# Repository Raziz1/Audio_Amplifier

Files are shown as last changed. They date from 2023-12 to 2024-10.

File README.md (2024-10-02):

# Audio_Amplifier 🔊
Designing a push–pull audio amplifier for a car speaker

## Goal 🎯
The goal of this project was to design a simple audio amplifier to drive a 4-ohm, 30-watt RMS (42 Watt peak) speaker extracted from a car door. The objective was not to create the most efficient design, but rather to explore various design approaches.

<p align="center">
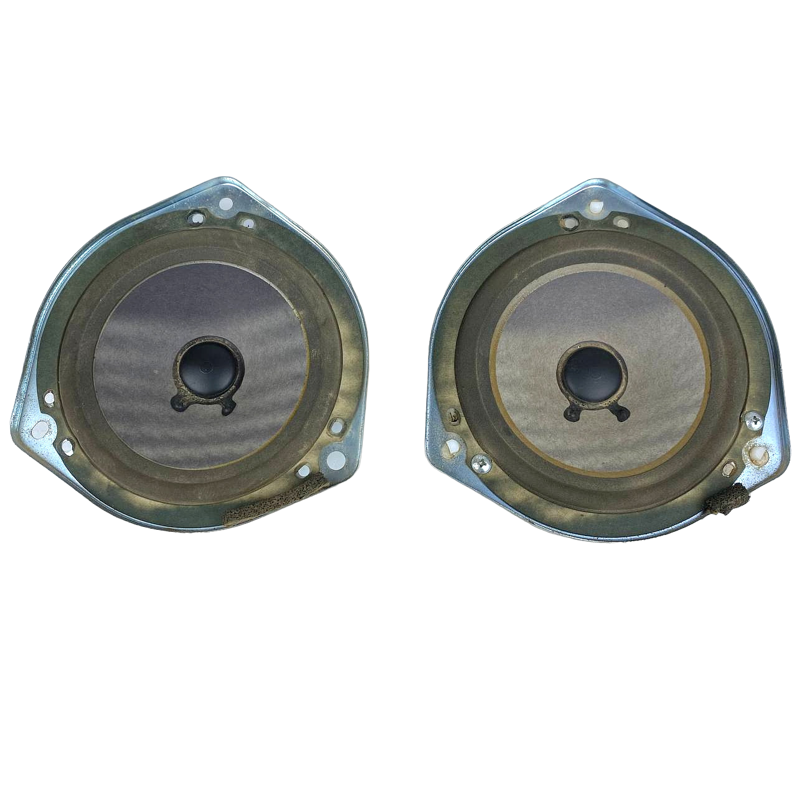
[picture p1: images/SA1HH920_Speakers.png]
  
</p>

## To-do List 📃
- [x] Pick amplifier class
- [x] Pick power stage amplifier
- [x] Design and simulate in LTSPICE
- [x] Pick components with appropriate ratings
- [x] Determine thermal output of transistors
- [x] PCB design
- [ ] Testing

## History 📃
Initially, I began by driving the speaker with my USB oscilloscope/waveform generator (Analog Discovery 2). The USB waveform generator has the ability to take an MP3 file as an input and output the corresponding waveform. It also has the ability to amplify the signal up to a peak voltage of 5V. However, there were a few problems with this:
1. According to the datasheet, this waveform generator has the ability to output a maximum current of 750mA. At a peak voltage of 5V, the power output would only be (0.75A x 5V = 3.75W peak * 0.707 = 2.65W RMS) 2.65 watts RMS, which is only about 9% of the speaker's power output capabilities
2. When set to 5V peak output, the waveform generator only seemed to be able to push out 250mA. This means we were only achieving a power output of (0.25A * 5V = 1.25W peak * 0.707 = 0.883W RMS) 0.883 watts RMS.
3. Lastly, when set to 5V, the speaker seemed to suffer from a lot of distortion and resulted in very muddy tones
4. The final motivation was to see if I could drive the speaker significantly louder. With a 1V waveform signal the loudest sound seemed to be around *INSERT DB MEASUREMENT*

## Constraints ⚠️
While devising the design for this project, I established a few constraints to prevent overcomplication. The constraints/rules I settled on were as follows:
* The input/audio signal would be anywhere from 100mV to 1V
* I didn't have to make use of the full 30 watt power capabilities of the speaker

# Audio Amplifier Background
To drive a speaker louder (higher output power) there are two things to keep in mind. These elements are evident in the power equation $P = V × I$. To acheive a higher output power we must amplify both voltage and current. Achieving greater output power necessitates amplifying both voltage and current. Therefore, we divide our amplifier design into two stages: the voltage/signal amplifier stage and the current/power amplifier stage. This practice is widely employed in all types of audio amplifiers.

The subsequent step in the process involved determining the preferred classification of audio amplifiers for this design. There are four main classes: A, B, AB, and Class D. Further information about these classifications can be found in the links provided below.

<p align="center">
  
</p>

### Class A Amplifiers
* Transistors conduct over the entire 360° cycle of the input signal
* Highest linearity and fidelity, with minimal crossover distortion
* Very inefficient, with typical efficiency around 25% due to constant current draw
* Significant heat dissipation and power wastage, even with no input signal
* Used in low-power applications where sound quality is the top priority

### Class B Amplifiers
* Use a pair of transistors, each conducting for 180° of the input signal cycle
* Improved efficiency over Class A, up to 78% theoretical maximum
* Suffer from crossover distortion around the zero-crossing point when transitioning between transistors
* Reduced heat dissipation compared to Class A
* Used in applications where efficiency is more important than linearity

### Class AB Amplifiers
*Combine the high efficiency of Class B with the low distortion of Class A
* Bias both transistors to conduct for slightly more than 180° to eliminate crossover distortion
* Efficiency up to 60%, lower than Class B but higher than Class A
* Moderate heat dissipation, less than Class A but more than Class B
* Popular choice for high-fidelity audio amplifiers, balancing efficiency and sound quality

I ended up settling on designing a Class AB amplifier due to its compromise between efficiency and fidelity.

The second decision was whether to use MOSFETs or BJTs for the power stage amplifier. I ultimately chose MOSFETs for the following reasons:
* They generally have high input impedance, which reduces the loading effect on the preceding stages
* They require no current to drive the gate pin
* They can switch faster than BJTs, which can be beneficial in certain applications
* Reduced distortion compared to some BJT designs
* The only drawback is they tend to be more expensive than BJT's

### Initial Class A Design
My initial design was based on the class A amplifier design, as shown in the image below. However, the issue arose from its excessive current draw from the op-amp. Additionally, in the absence of a signal input, the amplifier continues to conduct large amounts of current, which could potentially damage the speaker.

<p align="center">
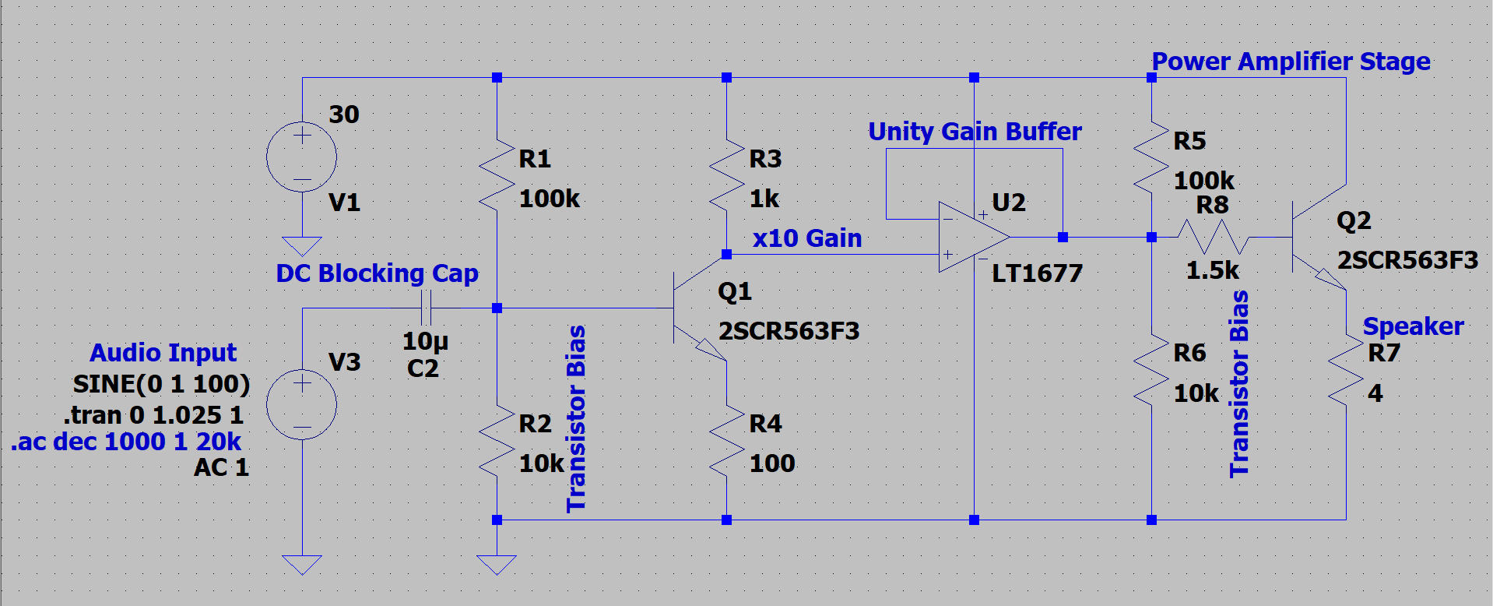
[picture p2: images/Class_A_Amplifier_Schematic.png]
  
  <p align="center"><small><i>Class A Amplifier Design in LTSpice</i></small</p>
</p>

<p align="center">
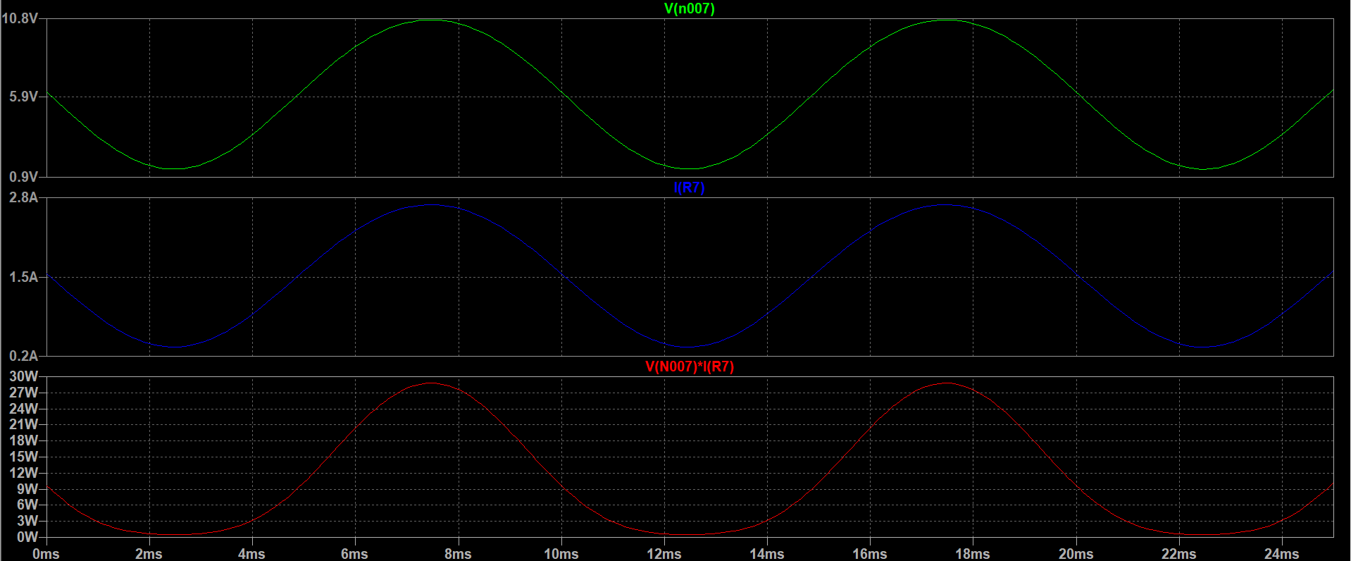
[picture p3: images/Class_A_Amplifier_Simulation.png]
  
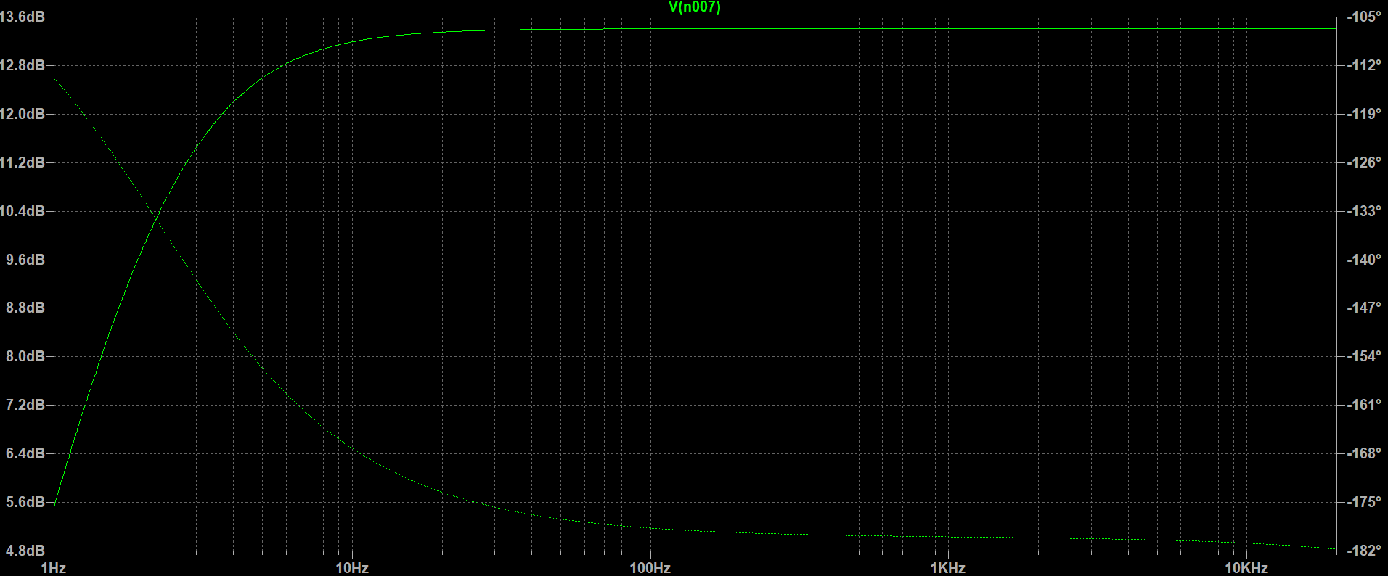
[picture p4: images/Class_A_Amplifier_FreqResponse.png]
  

  <p align="center"><small><i>Class A Amplifier Simulation in LTSpice</i></small</p>
</p>

# Final Class AB Design
## Schematic
<p align="center">
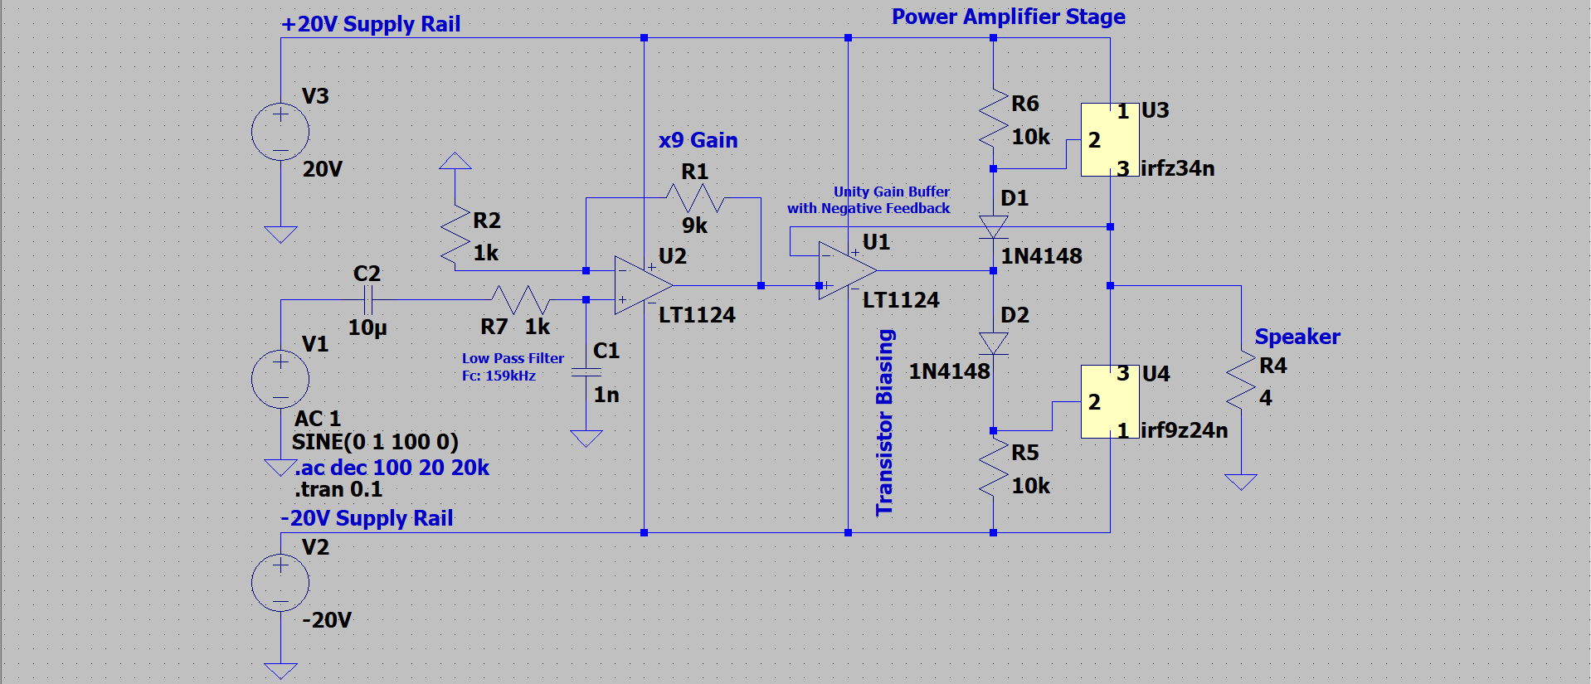
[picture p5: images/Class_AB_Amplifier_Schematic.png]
  
  <p align="center"><small><i>Class AB Amplifier LTSpice Schematic Capture</i></small></p>
</p>

* For this design, I ended up choosing the LT1124 op-amp for the signal amplifying stage. There were a couple of reasons behind this decision. Initially, I had planned for that stage to use a common emitter amplifier. However, the issue was that it required fine-tuning to determine the bias voltages. Additionally, by using the LT1124 op-amp, I could incorporate a potentiometer for variable gain ranging from 0 to 10dB.
* For the power stage of this amplifier, I ended up utilizing the op-amp's inverting terminal as a negative feedback loop for the push-pull configuration. This allowed me to avoid fine-tuning the bias voltages with resistors and diodes.

## Simulation
<p align="center">
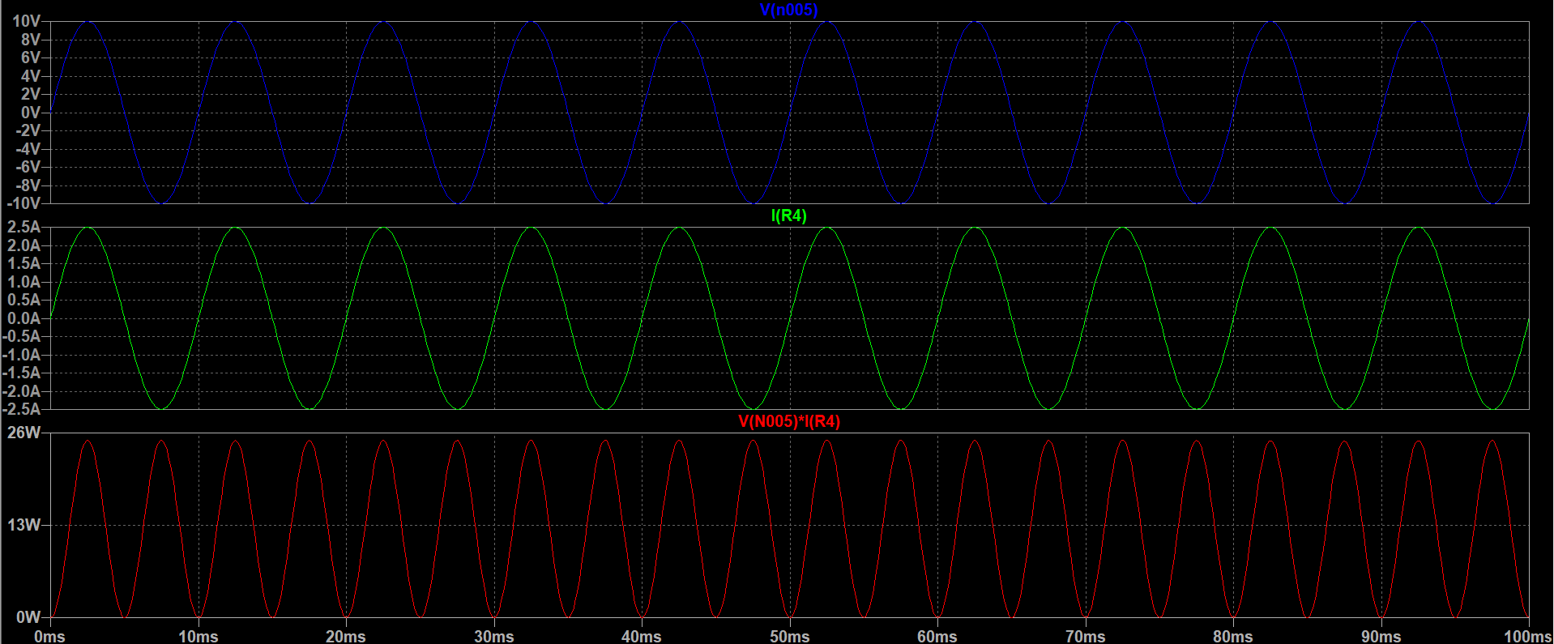
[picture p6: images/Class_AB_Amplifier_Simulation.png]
  
  <p align="center"><small><i>[1]Output Voltage [2]Output Current [3]Output Power</i></small</p>
</p>

<p align="center">
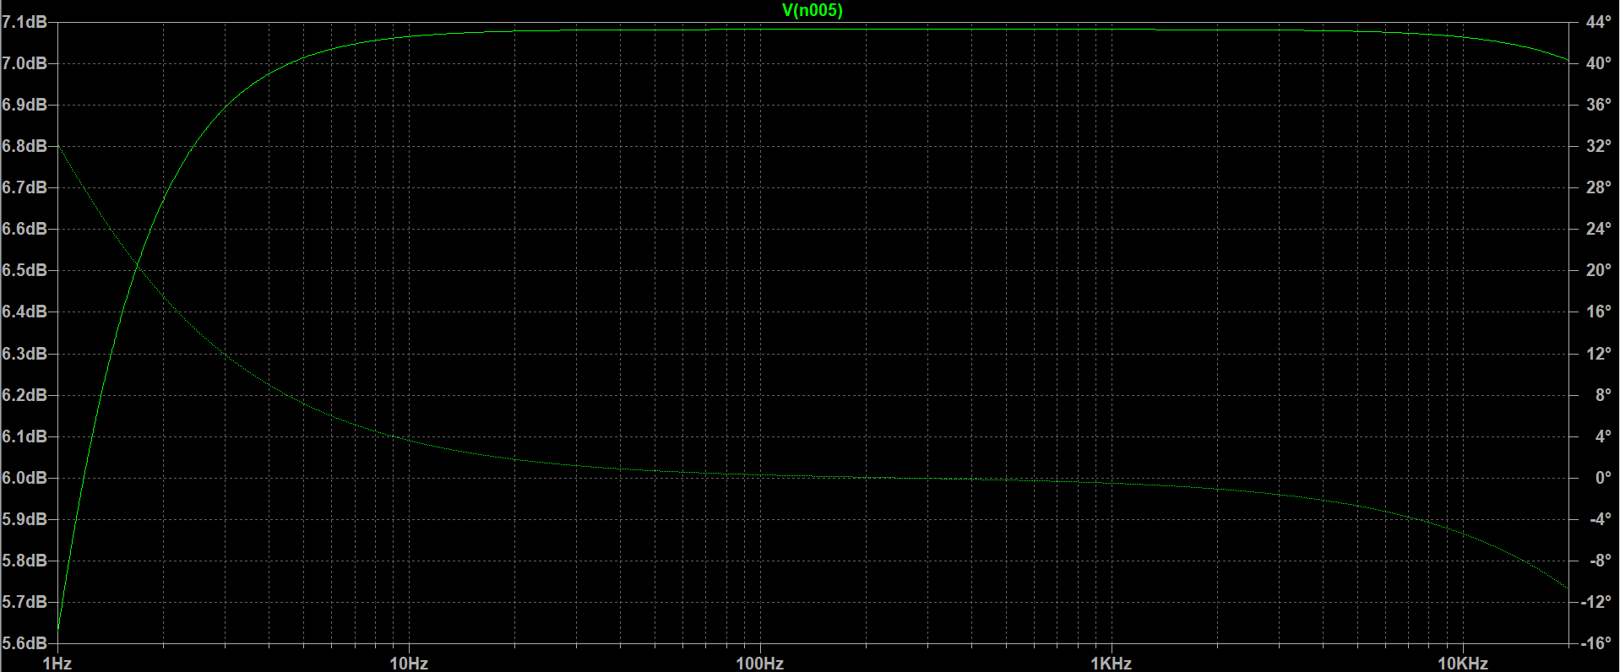
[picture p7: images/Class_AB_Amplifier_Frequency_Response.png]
  
  <p align="center"><small><i>Amplifier Frequency Response 1Hz - 20kHz</i></small</p>
</p>

* For the spice simulation of the MOSFETs, custom models were obtained online through Infineon's website. The custom models can be found in the *spice_models* folder.

# Parts
## OP-AMP
I ended up settling on the [LT1124](https://www.analog.com/en/products/lt1124.html)
* Power supply range: ±22V (Dual rail supplies)
* Slew rate: 3.9 - 4.5 V/us
  * To maintain high fidelity audio it is recommended to have a slew rate of +5V/us.
  * We can determine the minimum slew rate given the expected output voltage and frequency. Our maximum output voltage should be 10V and our maximum frequency should be around 20kHz (The upper limit of human hearing). Using the slew rate formula ($Slew Rate = 2πfv$)
  * $Minimum Slew Rate = 2 * π * 20000 * 10 = 1.256V/μS$ 
* Gain-Bandwidth product: 12.5MHz
* Low voltage noise: 2.7nV/√Hz Typ

## N-MOSFET
I ended up settling on the [IRFZ34NPBF](https://www.digikey.ca/en/products/detail/infineon-technologies/IRFZ34NPBF/811724)
* Maximum VDS: 55V
* Continuous drain current: 29A
* Maximum power dissipation: 68W
  * No additional cooling is required since we will not exceed this power rating
* Gate to source voltage: ±20V
* Gate threshold voltage: 2-4V
* RDS(ON): 0.04 ohms
* Turn-on delay time: 7ns
* Rise time: 49ns
* Turn-off delay time: 31ns
* Fall time: 40ns
* Input capacitanceL 700pF

## P-MOSFET
I ended up settling on the [IRF9Z24NPBF](https://www.digikey.ca/en/products/detail/infineon-technologies/IRF9Z24NPBF/811747)
* Maximum VDS: -55V
* Continuous drain current: -12A
* Maximum power dissipation: 45W
  * No additional cooling is required since we will not exceed this power rating
* Gate to source voltage: ±20V
* Gate threshold voltage: (-2V)-(-4V)
* RDS(ON): 0.175 ohms
* Turn-on delay time: 13ns
* Rise time: 55ns
* Turn-off delay time: 23ns
* Fall time: 37ns
* Input capacitanceL 350pF

*Both MOSFET's chosen are overkill for our purposes but provide sufficient headroom for error and/or future upgrades*

## N-MOSFET Junction Temperature Calculation
$Pavg = (Irms^2 * Rds(on))/2$
 * $Irms = Ipeak/√2 = 3A / √2 = 2.12A$
 * Rds(on) = 0.040 ohms
 * $Pavg = (2.12^2A * 0.04ohms)/2 = 0.08988 W$

$Tj = Pavg * RthJA + TA$
 * $Pavg = 0.08988W$
 * $RthJA = 62W/C$
 * $TA = 25C$
 * $Tj = 0.08988W * 62W/C + 25C = 30.57C$

## P-MOSFET Junction Temperature Calculation
$Pavg = (Irms^2 * Rds(on))/2$
 * $Irms = Ipeak/√2 = 3A / √2 = 2.12A$
 * Rds(on) = 0.175 ohms
 * $Pavg = (2.12^2A * 0.175ohms)/2 = 0.3932W$
 
$Tj = Pavg * RthJA + TA$
 * $Pavg = 0.3932$
 * $RthJA = 62W/C$
 * $TA = 25C$
 * $Tj = 0.3932W * 62W/C + 25C = 49.38C$

Based on the above calculations the MOSFETs shouldn't require any additional cooling methods.

# Power Supply Consideration
This design requires a positive and negative supply of 20V. This can be done using two power supplies and setting the ground references appropriately as described in this website ([Get a positive and negative voltage output from power supply](https://forum.digikey.com/t/get-a-positive-and-negative-voltage-output-from-power-supply/10593)). Alternatively, a split power supply design is another approach; however, the desired voltage and current specifications are simply too large for any regulators on the market.

## DC Bias Alternative
Since I only had a single power supply at home, I decided to provide an alternative circuit that utilizes a single supply and injects a DC bias voltage into the audio signal. The signal is then passed through a unity gain buffer and subsequently to the push-pull amplifier configuration. The push-pull amplifier configuration serves as a power stage amplifier, enabling us to deliver more power to the speaker. Finally, a large high-pass filter is added at the end to eliminate the initial DC bias.

### DC Bias Schematic 
<p align="center">
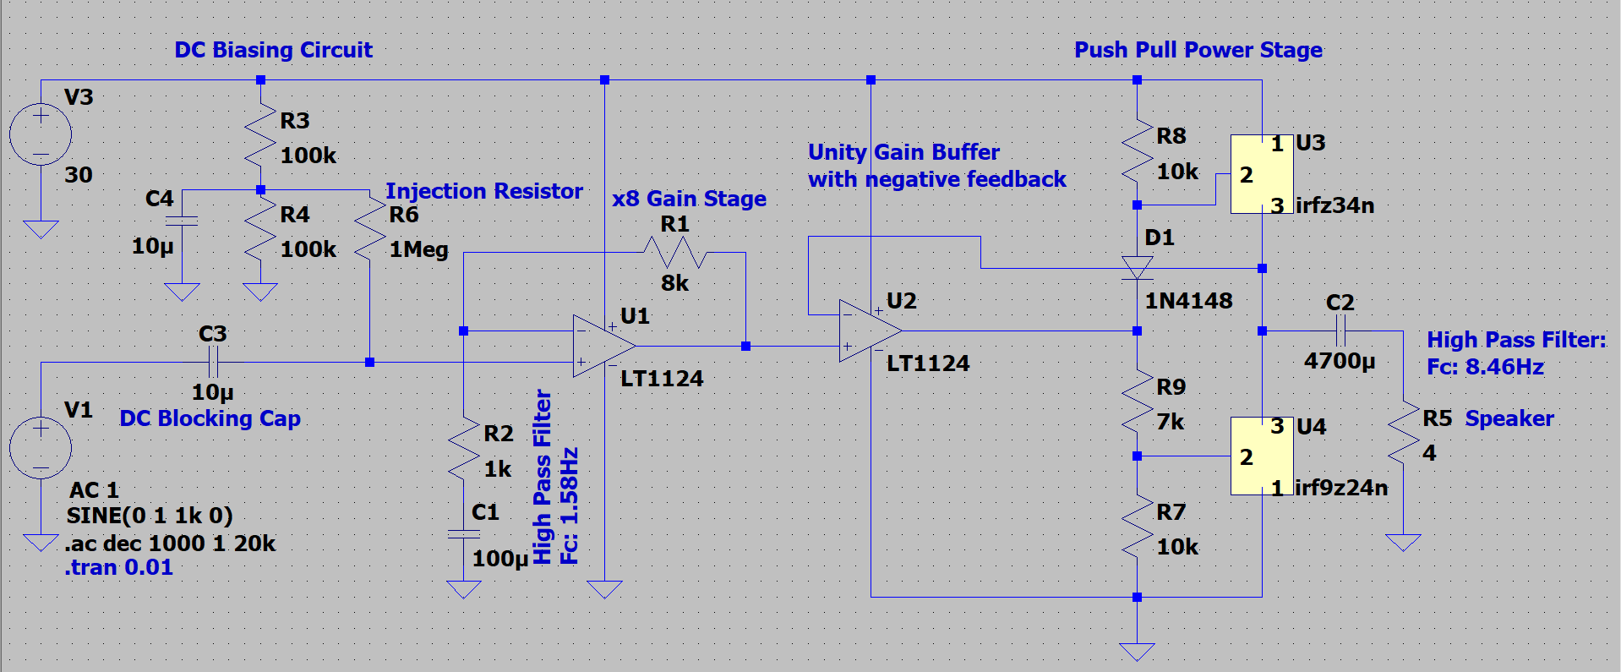
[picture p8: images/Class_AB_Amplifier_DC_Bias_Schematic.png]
  
  <p align="center"><small><i>Class AB Amplifier with DC Bias LTSpice Capture</i></small></p>
</p>

### DC Bias Simulation
<p align="center">
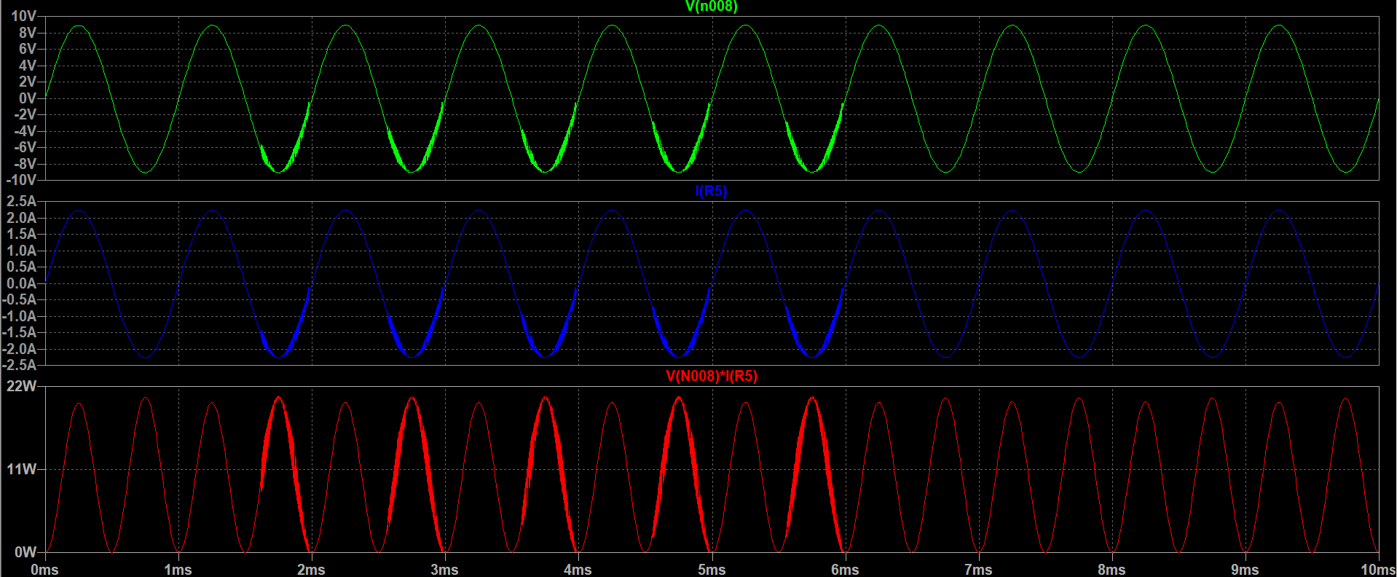
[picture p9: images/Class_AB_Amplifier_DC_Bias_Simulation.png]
  
  <p align="center"><small><i>[1]Output Voltage [2]Output Current [3]Output Power</i></small></p>
</p>

### DC Bias Frequency Response
<p align="center">
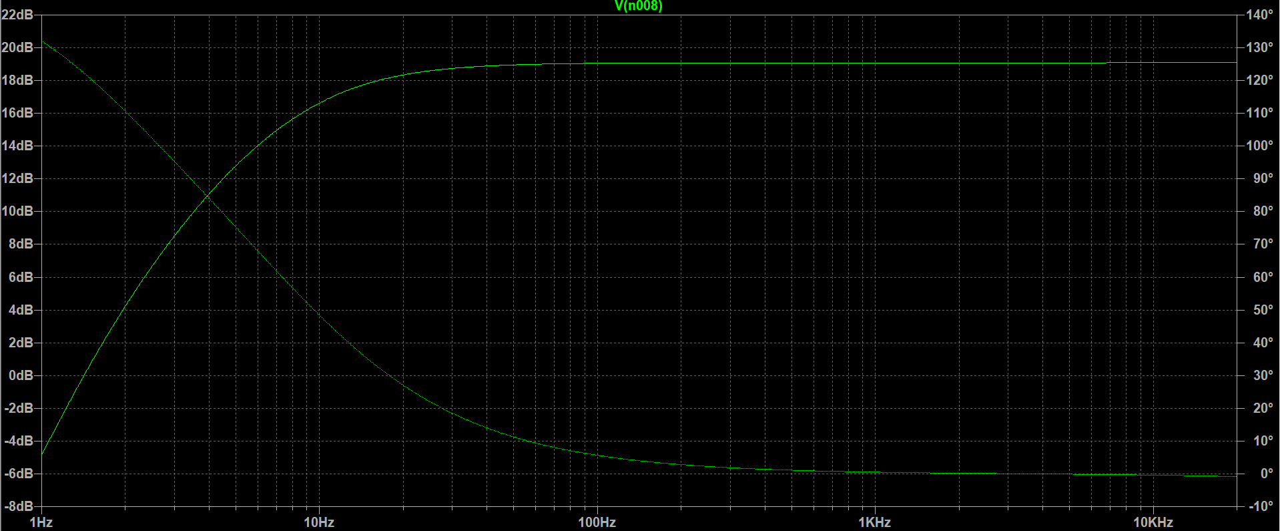
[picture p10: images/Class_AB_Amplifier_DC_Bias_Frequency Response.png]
  
  <p align="center"><small><i>DC Bias Circuit Frequency Response (1Hz - 20kHz)</i></small></p>
</p>

# PCB
The PCB design shown below is for the audio amplifier with dual supplies (+20V and -20V).

## 3D View 
<p align="center">
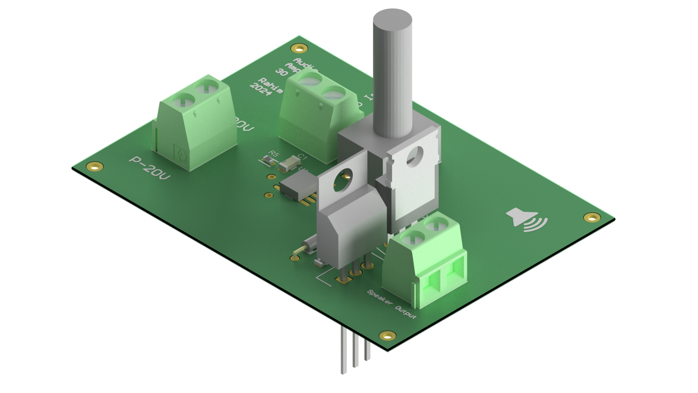
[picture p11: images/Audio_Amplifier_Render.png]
  
  <p align="center"><small><i>3D Audio Amplifier Render</i></small></p>
</p>

* One of the key considerations during this design was the use of power and ground planes. In this design, I settled on a 2 layer board design because it was cheap and simple to design. The layers are relatively thick to allow for large amounts of current to pass through the traces. However, the board might have benefited from a +20V, -20V, and GND planes. This would help dissipate heat better and reduce electromagnetic interference. 

## Power Integrity
<p align="center">
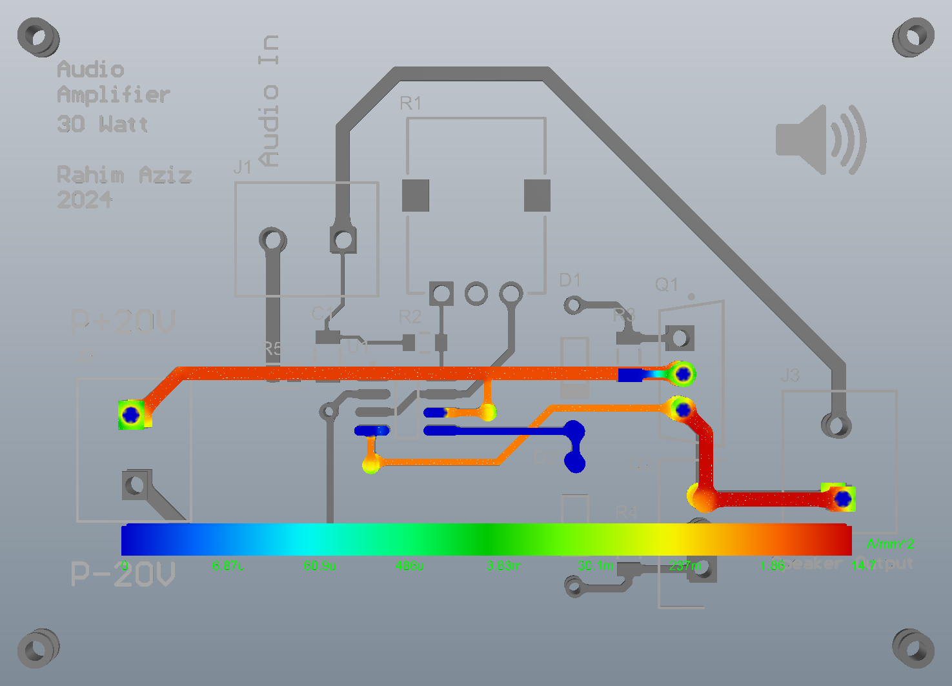
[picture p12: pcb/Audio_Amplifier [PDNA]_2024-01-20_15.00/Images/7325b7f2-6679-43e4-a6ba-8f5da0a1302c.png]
  
  <p align="center"><small><i>Power Analyzer by Keysight - Altium</i></small></p>
</p>

* I used the Saturn PCB Design Toolkit to determine the amount of current that the VIAs could handle. Based on power integrity simulations, the VIAs were more than capable of meeting the current requirements. Nevertheless, I ended up adding extra headroom for the current by increasing both the trace width and PCB thickness.

# Resources
* [Amplifier Series](https://www.youtube.com/watch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)
* [Online Circuit Simulator](https://www.falstad.com/circuit/)
* [Introduction to the Amplifier](https://www.electronics-tutorials.ws/amplifier/amp_1.html)
* [Audio Amplifier Basics](https://www.youtube.com/watch?v=U0FIG2J6Zls&ab_channel=TexasInstruments)
* [Power Amplifiers](https://en.wikipedia.org/wiki/Power_amplifier_classes#Class_C)

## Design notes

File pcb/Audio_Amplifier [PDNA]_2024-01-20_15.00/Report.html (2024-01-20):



Power Analyzer Results Report for
Audio_Amplifier

Power Analyzer Version: 1.0.16.227
Report Time / Date: 2024-01-20 2:59:55 PM
Project Name: Audio_Amplifier
Used Simulation Engine: Keysight

Power Analizer Global Settings

Parameter | Value
Metal conductivity | 58800 S/mm
Metal base conductivity | 58800 S/mm
Metal base temperature | 25°C
Metal work temperature | 25°C
Metal temperature coefficient | 0.4 %/°C
Conductor Max Current Density for Surfase Layers | 100 A/mm^2
Conductor Max Current Density for Internal Layers | 100 A/mm^2
Via wall thickness | 0.01778mm
Max Via Current Density | 0 A/mm^2
Skip ground | True

Design Stackup

# | Name | Material | Type | Thickness

| Top Overlay | | Overlay
| Top Solder | Solder Resist | Solder Mask | 0.01016mm
1 | Top Layer | | Signal | 0.2032mm
| Dielectric 1 | Core-029 | Core | 0.6096mm
2 | Bottom Layer | | Signal | 0.2032mm
| Bottom Solder | Solder Resist | Solder Mask | 0.01016mm
| Bottom Overlay | | Overlay

Full Report

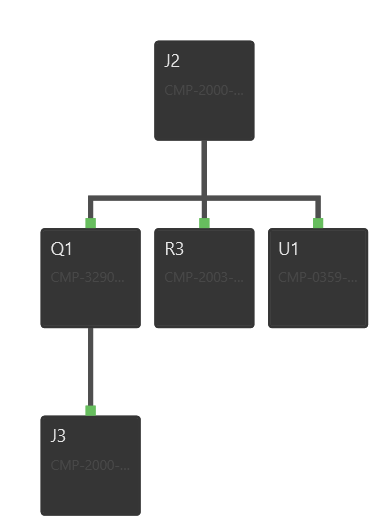
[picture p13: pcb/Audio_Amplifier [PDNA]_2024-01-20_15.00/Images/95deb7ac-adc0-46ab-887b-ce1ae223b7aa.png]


P+20V

Heatmap For Current Density

Layer: Bottom Layer


Layer: Top Layer


Heatmap For Voltage Drop

Layer: Bottom Layer


Layer: Top Layer


System-Level Power Network Results

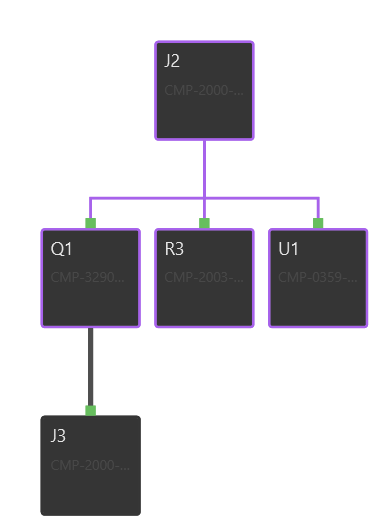
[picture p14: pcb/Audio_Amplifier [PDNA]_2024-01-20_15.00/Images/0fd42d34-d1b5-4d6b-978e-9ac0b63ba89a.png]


Network P+20V Details

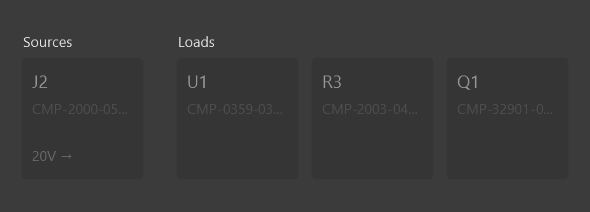
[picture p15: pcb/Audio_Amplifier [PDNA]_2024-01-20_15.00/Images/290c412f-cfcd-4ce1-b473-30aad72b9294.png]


Power Analysis Pass/Fail: Pass

Power Consumption for This Network: 0 Watts

Least Margins:

Margin Type | Absolute | Pass/Fail
Non-Via Current Density (A/mm^2) | 85.329 | Pass
Via Current (A) | 1.5745 | Pass

Margin Type (%) | Percent | Pass/Fail
Non-Via Current Density | 85.33% | Pass
Via Current | 41.48% | Pass

Failed Via Summary:

Net | Location | Drill Diameter | Max Current (A) | Actual Current (A) | Margin (%) | Max Current Density | Actual Current Density | Margin (%)
Negative_Feedback | 51.575mm : 40.85mm | 0.7112mm | 2.74 | 200.35m | 92.69% | 0 (A/mm^2) | 18.363 (A/mm^2) | ∞
P+20V | 59.85mm : 44.575mm | 0.7112mm | 2.74 | 207.17m | 92.44% | 0 (A/mm^2) | 18.988 (A/mm^2) | ∞
P+20V | 34.6mm : 44.39mm | 1.3mm | 3.8328 | 1.0771 | 71.90% | 0 (A/mm^2) | 9.8511 (A/mm^2) | ∞
P+20V | 73.67mm : 47.3mm | 1.2mm | 3.6472 | 869.97m | 76.15% | 0 (A/mm^2) | 9.3392 (A/mm^2) | ∞
Negative_Feedback | 75.25mm : 38.415mm | 1.28mm | 3.7957 | 2.2212 | 41.48% | 0 (A/mm^2) | 20.952 (A/mm^2) | ∞
Negative_Feedback | 73.67mm : 44.76mm | 1.2mm | 3.6472 | 423.04m | 88.40% | 0 (A/mm^2) | 4.5419 (A/mm^2) | ∞
Negative_Feedback | 84.95mm : 38.46mm | 1.3mm | 3.8328 | 439.1m | 88.54% | 0 (A/mm^2) | 4.0178 (A/mm^2) | ∞
NetD1_2 | 66.075mm : 40.95mm | 0.85mm | 2.9976 | 7.4118n | 100.00% | 0 (A/mm^2) | 370.76n (A/mm^2) | ∞
NetD1_2 | 66.05mm : 43.225mm | 0.85mm | 2.9976 | 5.6364n | 100.00% | 0 (A/mm^2) | 244.63n (A/mm^2) | ∞

Negative_Feedback

Heatmap For Current Density

Layer: Bottom Layer
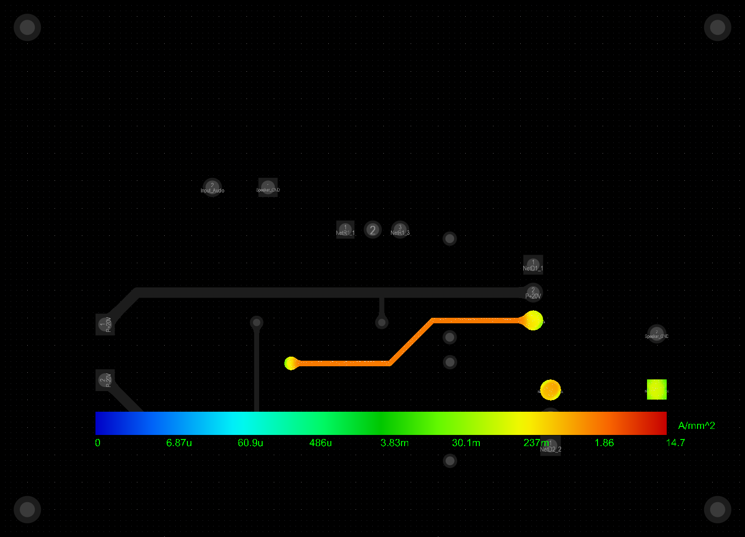
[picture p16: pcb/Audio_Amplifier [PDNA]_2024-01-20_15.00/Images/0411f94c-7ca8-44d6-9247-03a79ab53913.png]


Layer: Top Layer


Heatmap For Voltage Drop

Layer: Bottom Layer
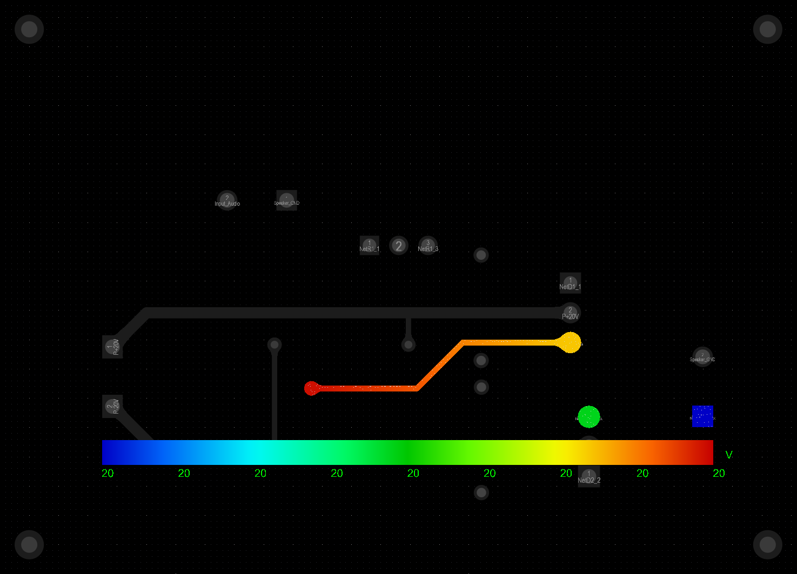
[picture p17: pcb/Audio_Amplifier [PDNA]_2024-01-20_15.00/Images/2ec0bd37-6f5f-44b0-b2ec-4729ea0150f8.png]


Layer: Top Layer
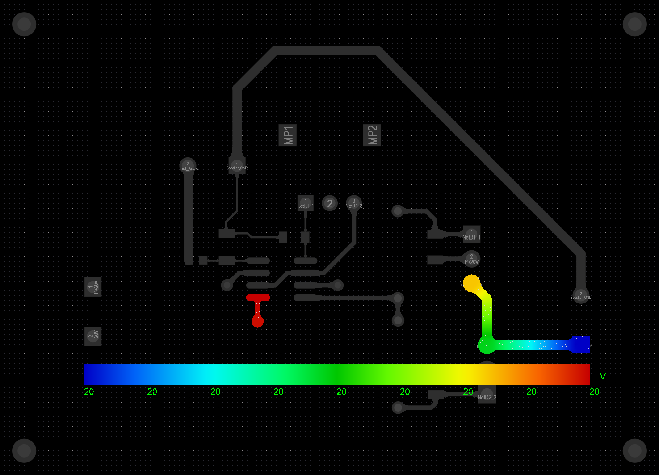
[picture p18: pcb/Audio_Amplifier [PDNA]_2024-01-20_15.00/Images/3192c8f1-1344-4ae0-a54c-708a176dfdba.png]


System-Level Power Network Results



Network Negative_Feedback Details



Power Analysis Pass/Fail: Pass

Power Consumption for This Network: 0 Watts

Least Margins:

Margin Type | Absolute | Pass/Fail
Non-Via Current Density (A/mm^2) | 85.329 | Pass
Via Current (A) | 1.5745 | Pass

Margin Type (%) | Percent | Pass/Fail
Non-Via Current Density | 85.33% | Pass
Via Current | 41.48% | Pass

Failed Via Summary:

Net | Location | Drill Diameter | Max Current (A) | Actual Current (A) | Margin (%) | Max Current Density | Actual Current Density | Margin (%)
Negative_Feedback | 51.575mm : 40.85mm | 0.7112mm | 2.74 | 200.35m | 92.69% | 0 (A/mm^2) | 18.363 (A/mm^2) | ∞
Negative_Feedback | 75.25mm : 38.415mm | 1.28mm | 3.7957 | 2.2212 | 41.48% | 0 (A/mm^2) | 20.952 (A/mm^2) | ∞
Negative_Feedback | 73.67mm : 44.76mm | 1.2mm | 3.6472 | 423.04m | 88.40% | 0 (A/mm^2) | 4.5419 (A/mm^2) | ∞
Negative_Feedback | 84.95mm : 38.46mm | 1.3mm | 3.8328 | 439.1m | 88.54% | 0 (A/mm^2) | 4.0178 (A/mm^2) | ∞

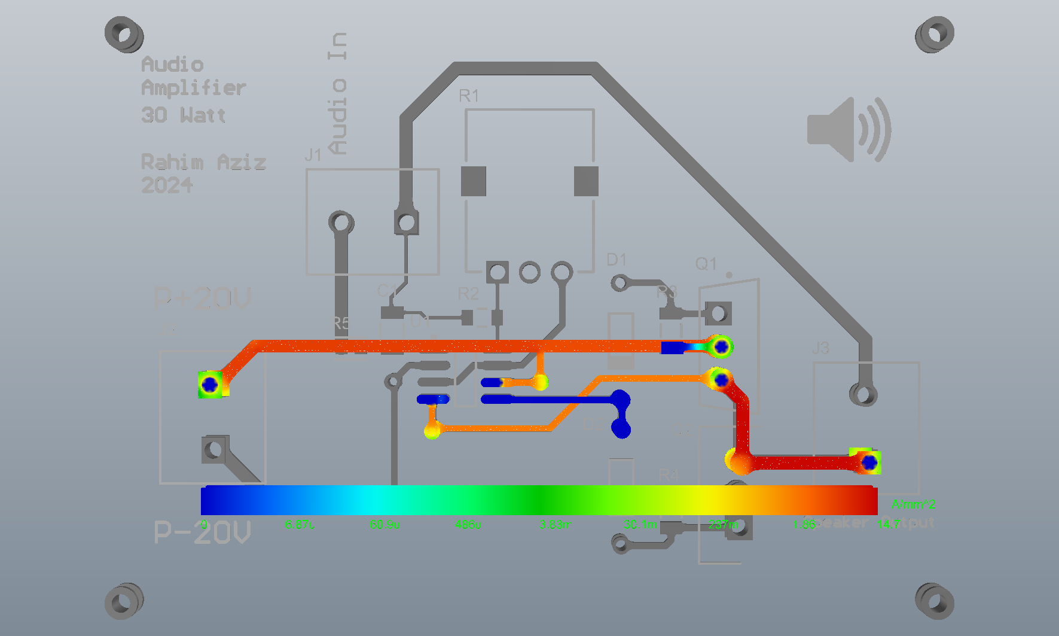
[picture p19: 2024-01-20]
pcb/Audio_Amplifier [PDNA]_2024-01-20_15.00/Images/6e913c12-4732-4104-ac73-5536e27b1194.png

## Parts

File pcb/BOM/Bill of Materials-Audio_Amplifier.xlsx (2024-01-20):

Line # | Name | Description | Designator | Revision ID | Revision State | Revision Status | Quantity | Manufacturer 1 | Manufacturer Part Number 1 | Manufacturer Lifecycle 1 | Supplier 1 | Supplier Part Number 1 | Supplier Unit Price 1 | Supplier Subtotal 1
 | C1206C102K4RACTU | CAP CER 1000PF 16V 10% X7R 1206 | C1 | CMP-1037-02436-2 | New From Design | Up to date | 1 | KEMET | C1206C102K4RACTU | Volume Production | Newark | 96Y7234 | 0.034 | 0.034
 | 1N4148 | High-speed Diode, 100 V, 450 mA, 2-Pin SOD27, RoHS | D1, D2 | CMP-0648-00002-1 | Released | Up to date | 2 | NXP Semiconductors | 1N4148 | Volume Production | Digikey | 1N4148FS-ND | 0.1 | 0.2
 | 1729128 | PCB Terminal Block, 13.5 A, 400 V, 2-Pin THD, RoHS, Bulk | J1, J2, J3 | CMP-2000-05815-1 | Released | Up to date | 3 | Phoenix Contact | 1729128 | Volume Production | Arrow Electronics | 1729128 | 0.8926 | 2.68
 | IRFZ34NPBF | MOSFET N-CH 55V 29A TO220AB | Q1 | CMP-32901-000547-1 | New From Design | Up to date | 1 | Infineon | IRFZ34NPBF | Volume Production | Newark | 63J7120 | 0.244 | 0.244
 | IRF9Z24NPBF | Infineon IRF9Z24NPBF P-channel MOSFET Transistor, 12 A, 55 V, 3-Pin TO-220AB | Q2 | CMP-041-000000-2 | Draft | Up to date | 1
 | P090S-14T20BR10K | 9 mm Rotary Potentiometer, Insulated Shaft, Conductive Plastic Element, 10 KOhm, -20 to 70 degC, 3-Pin THD, RoHS, Tray | R1 | CMP-2000-06871-1 | Released | Up to date | 1 | TT BI | P090S-14T20BR10K | Volume Production | Newark | 46M2481 | 0.6 | 0.6
 | RC2012F102CS | Res Thick Film 0805 1kΩ 1% 0.125W ±100ppm/°C Molded SMD T/R | R2 | CMP-13261-003265-1 | New From Design | Up to date | 1 | Samsung | RC2012F102CS | Volume Production
 | CRCW120610K0FKEA | RES Thick Film, 10kΩ, 1%, 0.25W, 100ppm/°C, 1206 | R3, R4 | CMP-2003-04807-2 | New From Design | Up to date | 2 | Vishay | CRCW1206-10K0FKEA | Volume Production
 | RC1608F1501CS | Res Thick Film 0603 1.5kΩ 1% 0.1W ±100ppm/°C Molded SMD T/R | R5 | CMP-13261-004935-1 | New From Design | Up to date | 1 | Samsung | RC1608F1501CS | Volume Production
 | LT1124CS8#PBF | Dual Channel, Rotated Pinout, Low Noise Precision Operational Amplifier, Low 1/f Corner, 12.5 MHz Typical GBW, 4.5 V/us Typical SR, 8 to 44 V, 8-Pin SOIC (S8-8), Commercial, Pb-Free | U1 | CMP-0359-03018-2 | Released | Up to date | 1 | Analog Devices / Linear Technology | LT1124CS8#PBF | Volume Production | Mouser | 584-LT1124CS8#PBF | 9.67 | 9.67

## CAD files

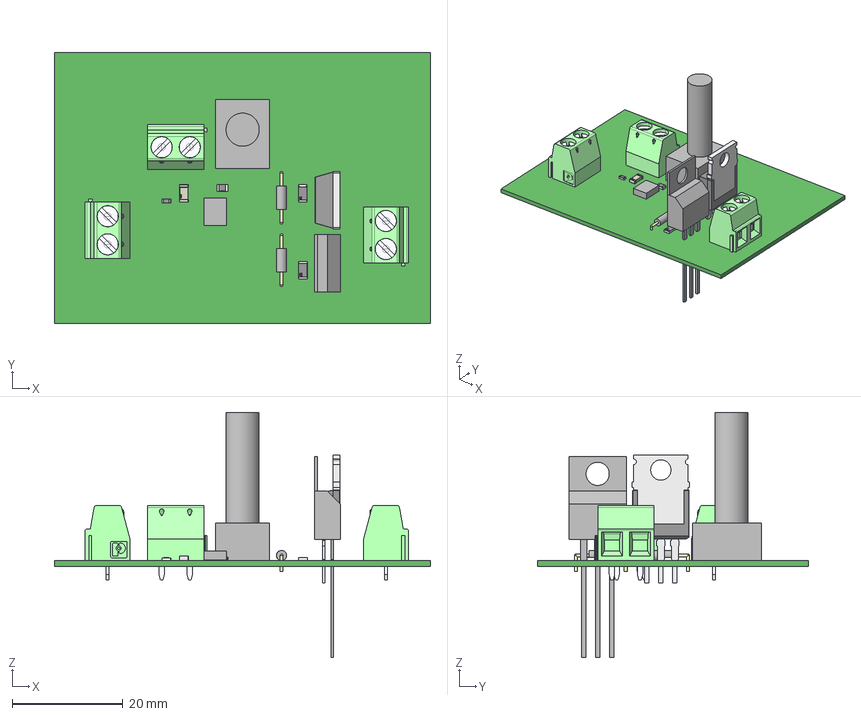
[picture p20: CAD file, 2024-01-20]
pcb/ExportSTEP/Audio_Amplifier.step
68.0 x 49.0 x 44.3 mm
Extruded x 2
Samsung Logo Yury adjustable
terminals x 3
top x 3
logo x 4
Tab
PinsArray
pins
mkdsn_1.5-2-5.08 x 3
Cap_KEMET_C1206C472K4RACTU_eec x 3

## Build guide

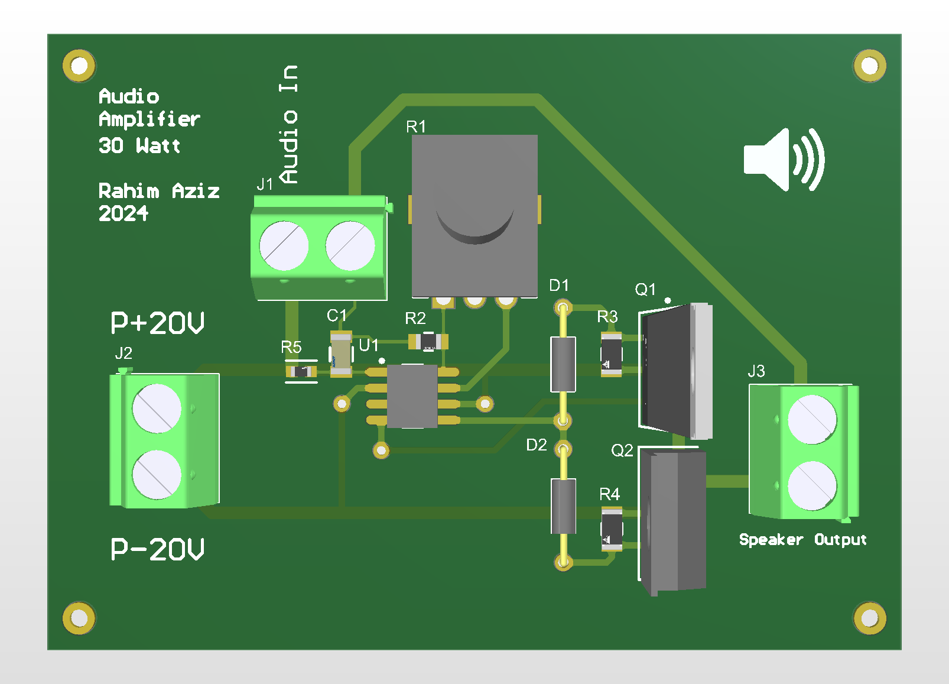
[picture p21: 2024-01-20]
pcb/PCB 3D Print/Audio_Amplifier.png

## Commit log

2024-01-19 Added single supply schematics
    * Added single supply schematic/simulation
    * Added custom spice models
2024-01-20 PCB files
    [Audio_Amplifier.GBL, Audio_Amplifier.GBO, Audio_Amplifier.GBP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]
